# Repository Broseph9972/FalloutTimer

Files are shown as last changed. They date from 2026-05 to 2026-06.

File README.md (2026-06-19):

# FalloutTimer
Zine


Casing v5

---
The FalloutTimer™ is a simple timer that uses an RTC, A pi Pico, Some buttons, and some cheap 7 segment displays to tell you how much time is left in Hack club fallout!
(Can be used for other things as well)
# Assembly

Assembly is relatively simple, Solder the pico, buttons, caps, and RTC, into the spots they appear on the pcb/zine. look at the zine for info about how to solder the 7-seg display, then flash the firmware by holding down the boot button on the pico while plugging it in. then compile the code and drop the uf2 into the pico's flash. it should reboot and work. Thats really all you need.
--- 
# Usage
Simply set the time via the buttons on the bottom. left button controls days and hrs, left controls mins. seconds are always set to zero for simplicity. if you click the left button it will change hrs, if u hold it down, then it will change days. Thats basically it.
---
## Why?
I decided to make it because i need more time for fallout and it seemed like a simple project i could do to increase my amount of approved hours. also it looks cool as wall deco. ill probably bring it to fallout to show the amount of time left
It displays the time left in fallout with Day,Hour,Minutes,Seconds, similar to the fallout website. also i might get it to check streaks too maybe? <- no wifi so probably not. u would need a pico w aswell.

|Name |Price|Link |Quantity|Notes |
|---|-----|---|---|---|
|7 Segment display |$2.77|https://www.aliexpress.us/item/2255801097197605.html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 |1 |Comes with 8 digits built in. built for 0.56" |
|Pi Pico |$0.99|https://www.aliexpress.us/item/3256806652932348.html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 |1 |Lots of fakes, shouldnt matter. get usb-c if u want|
|PCB |$7.12|JLCPCB.com |1 |Upload the gerber from the repo. |
|DS3231M RTC |$1.39|https://www.aliexpress.us/item/3256807808551126.html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|1 |so u dont gotta reset the clock everytime |
|100nF Cap |$1.58|https://www.aliexpress.us/item/3256802327709422.html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 |1 |Technically optional, but idk |
|Pushbuttons |$0.99|https://www.aliexpress.us/item/2251832687083572.html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 |2 |For input |
|3d printed parts (optional)|$0 |N/A |1 |Not needed but just there ig |

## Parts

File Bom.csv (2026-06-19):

Name | Price | Link | Quantity | Notes
7 Segment display | $2.77 | https://www.aliexpress.us/item/2255801097197605.html | 1 | Comes with 8 digits built in. built for 0.56"
Pi Pico | $0.99 | https://www.aliexpress.us/item/3256806652932348.html | 1 | Lots of fakes, shouldnt matter. get usb-c if u want
PCB | $7.12 | JLCPCB.com | 1 | Upload the gerber from the repo.
DS3231M RTC | $1.39 | https://www.aliexpress.us/item/3256807808551126.html | 1 | so u dont gotta reset the clock everytime
100nF Cap | $1.58 | https://www.aliexpress.us/item/3256802327709422.html | 1 | Technically optional, but idk
Pushbuttons | $0.99 | https://www.aliexpress.us/item/2251832687083572.html | 1 | For buttons
3d printed parts (optional) | $0 | N/A | 1 | Not needed but just there ig
M2 screws and bolts | $7.58 | https://a.co/d/0hszMEHz | 1 | For mounting the enclosure / parts

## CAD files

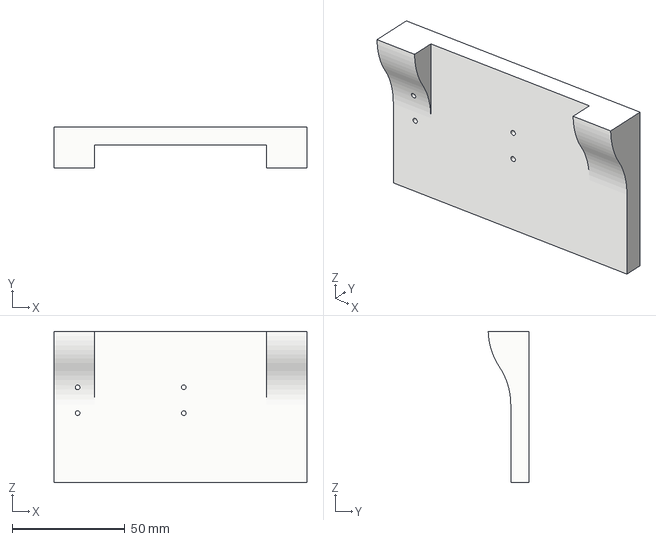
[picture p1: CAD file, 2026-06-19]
Cad/Casing.3mf
112.0 x 18.0 x 67.0 mm

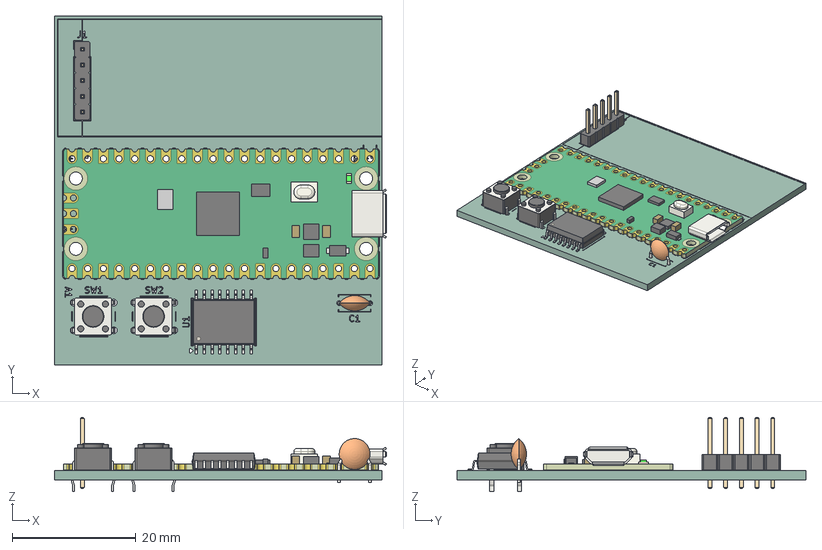
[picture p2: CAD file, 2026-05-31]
Cad/FalloutTimer.step
53.8 x 56.5 x 12.0 mm
SOIC-16W_7.5x10.3mm_P1.27mm
SW_PUSH_6mm x 2
C_Disc_D5.0mm_W2.5mm_P5.00mm
RaspberryPi_Pico_Module_KiCad
PinHeader_1x05_P2.54mm_Vertical
FalloutTimer_silkscreen x 2
FalloutTimer_PCB

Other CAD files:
Cad/Casing.f3d

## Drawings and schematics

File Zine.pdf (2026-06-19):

# FALLOUT TIMER!!

### Like this:

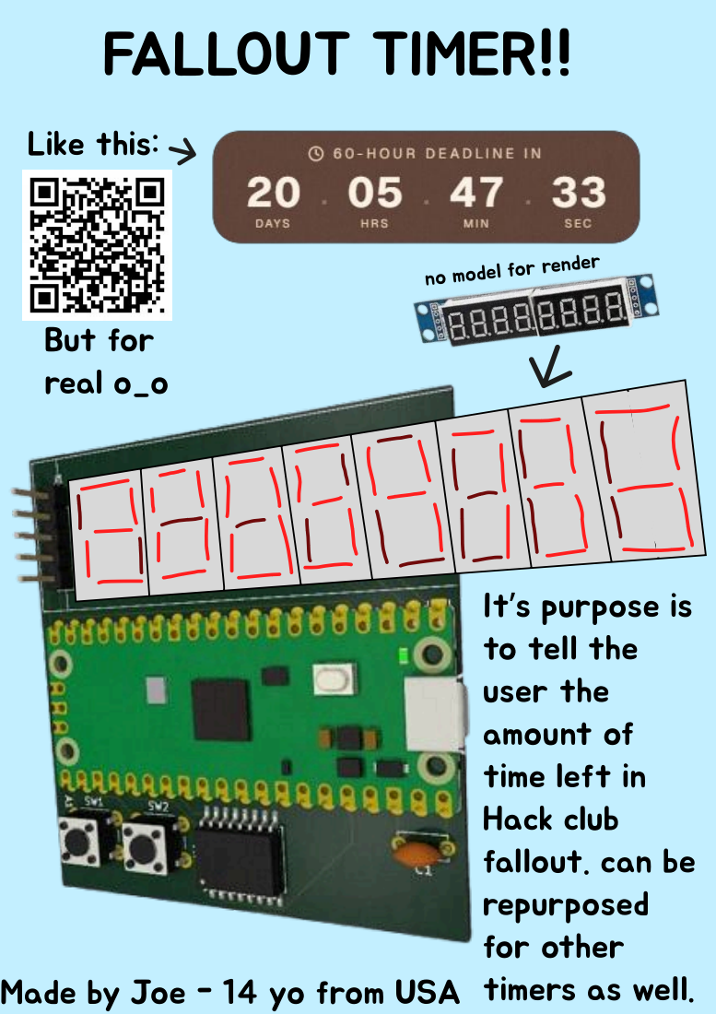
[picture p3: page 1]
But for; real o_o

no model for render

It’s purpose is
to tell the
user the
amount of
time left in
Hack club
fallout. can be
repurposed
for other
timers as well.

Made by Joe - 14 yo from USA

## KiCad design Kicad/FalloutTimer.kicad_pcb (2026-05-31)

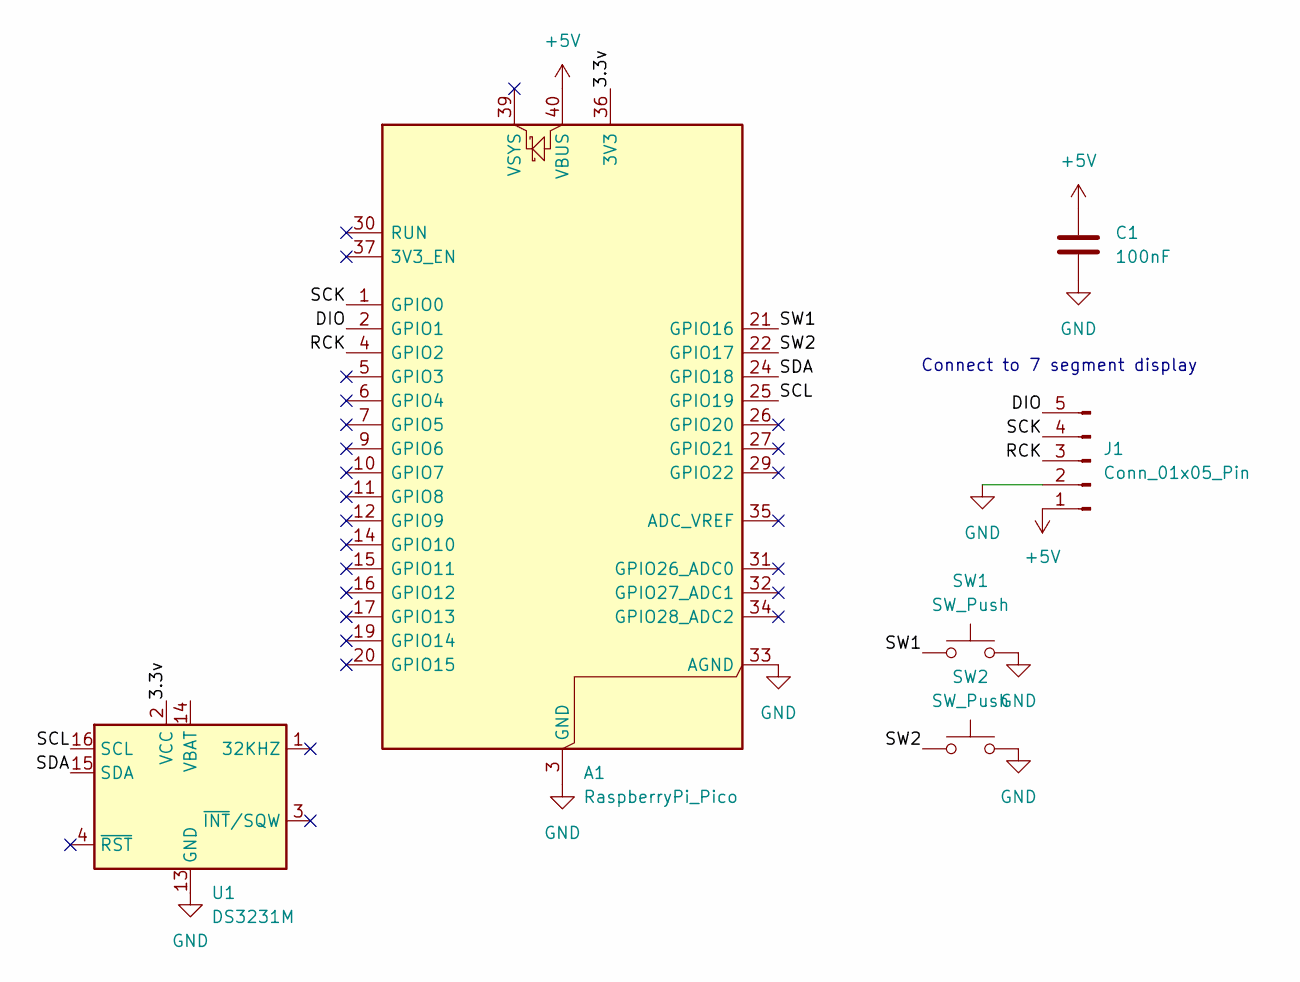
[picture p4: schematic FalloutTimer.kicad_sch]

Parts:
A1: RaspberryPi_Pico; RaspberryPi_Pico_Common_Unspecified
C1: 100nF; C_Disc_D5.0mm_W2.5mm_P5.00mm
J1: Conn_01x05_Pin; PinHeader_1x05_P2.54mm_Vertical
SW1, SW2: SW_Push; SW_PUSH_6mm
U1: DS3231M; SOIC-16W_7.5x10.3mm_P1.27mm

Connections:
+5V: A1.40 (VBUS), C1.1, J1.1
/3.3v: A1.36 (3V3), U1.2 (VCC)
/DIO: A1.2 (GPIO1), J1.5
/RCK: A1.4 (GPIO2), J1.3
/SCK: A1.1 (GPIO0), J1.4
/SCL: A1.25 (GPIO19), U1.16 (SCL)
/SDA: A1.24 (GPIO18), U1.15 (SDA)
/SW1: A1.21 (GPIO16), SW1.1
/SW2: A1.22 (GPIO17), SW2.1
GND: A1.3 (GND), A1.8 (GND), A1.13 (GND), A1.18 (GND), A1.23 (GND), A1.28 (GND), A1.33 (AGND), A1.38 (GND), C1.2, J1.2, SW1.2, SW2.2, U1.5 (GND), U1.6 (GND), U1.7 (GND), U1.8 (GND), U1.9 (GND), U1.10 (GND), U1.11 (GND), U1.12 (GND), U1.13 (GND)

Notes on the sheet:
Connect to 7 segment display

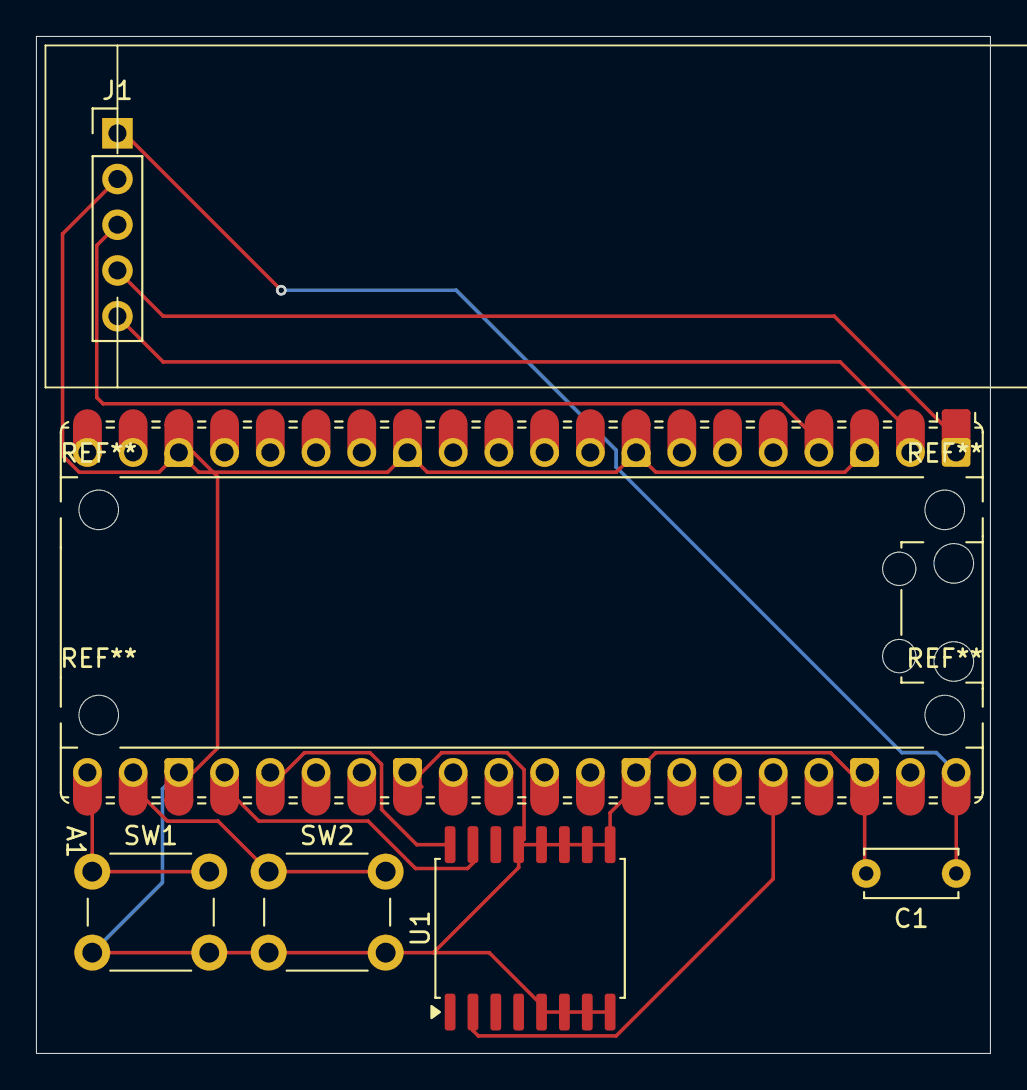
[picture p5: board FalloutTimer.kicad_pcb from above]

Board: 2 copper layers, 53.0 x 56.5 mm, 6 parts (0 on the bottom side), 10 nets.

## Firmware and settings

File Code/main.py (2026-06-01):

import board
import busio
import time
import digitalio
from adafruit_ds3231 import DS3231

# I2C for RTC (SDA=GPIO18, SCL=GPIO19)
i2c = busio.I2C(scl=board.GP19, sda=board.GP18)
rtc = DS3231(i2c)

# 74HC595 shift registers for 8 7-segment displays
# SCK=GPIO0 (clock), DIO=GPIO1 (data), RCK=GPIO2 (latch)
sck = digitalio.DigitalInOut(board.GP0)
sck.direction = digitalio.Direction.OUTPUT

dio = digitalio.DigitalInOut(board.GP1)
dio.direction = digitalio.Direction.OUTPUT

rck = digitalio.DigitalInOut(board.GP2)
rck.direction = digitalio.Direction.OUTPUT

# 7-segment display patterns (common cathode, DP on bit 7)
SEGMENTS = {
    0: 0b00111111,  # 0
    1: 0b00000110,  # 1
    2: 0b01011011,  # 2
    3: 0b01001111,  # 3
    4: 0b01100110,  # 4
    5: 0b01101101,  # 5
    6: 0b01111101,  # 6
    7: 0b00000111,  # 7
    8: 0b01111111,  # 8
    9: 0b01101111,  # 9
    10: 0b00000000  # blank
}

# Pushbuttons (GPIO16 and GPIO17, pulled to GND)
button_left = digitalio.DigitalInOut(board.GP16)
button_left.direction = digitalio.Direction.INPUT
button_left.pull = digitalio.Pull.UP

button_right = digitalio.DigitalInOut(board.GP17)
button_right.direction = digitalio.Direction.INPUT
button_right.pull = digitalio.Pull.UP

# Timer state (in seconds)
time_remaining = 0
setting_mode = False
blink_state = False
blink_time = 0
display_buffer = [10, 10, 10, 10, 10, 10, 10, 10]

def shift_out_byte(byte):
    """Shift out 8 bits to 74HC595"""
    for i in range(8):
        dio.value = (byte >> (7 - i)) & 1
        time.sleep(0.00005)
        sck.value = 1
        time.sleep(0.00005)
        sck.value = 0

def latch():
    """Latch data into output registers"""
    rck.value = 1
    time.sleep(0.0001)
    rck.value = 0

def shift_out_bytes(bytes_list):
    """Shift out multiple bytes (for chaining 74HC595s)"""
    for byte in reversed(bytes_list):  # Reverse for correct bit order
        shift_out_byte(byte)
    latch()

def seconds_to_display(seconds):
    """Convert seconds to day:hour:minute:second format"""
    days = seconds // 86400
    hours = (seconds % 86400) // 3600
    minutes = (seconds % 3600) // 60
    secs = seconds % 60
    return days, hours, minutes, secs

def update_display(days, hours, minutes, secs):
    """Update display buffer with DD:HH:MM:SS"""
    global display_buffer
    display_buffer = [
        days // 10,
        days % 10,
        hours // 10,
        hours % 10,
        minutes // 10,
        minutes % 10,
        secs // 10,
        secs % 10
    ]

def render_display():
    """Send display buffer to 74HC595s"""
    segments = [SEGMENTS.get(d, SEGMENTS[10]) for d in display_buffer]
    shift_out_bytes(segments)

def display_blink():
    """Blink display when timer reaches 0"""
    global blink_state, blink_time
    current_time = time.monotonic()
    if current_time - blink_time > 0.5:
        blink_state = not blink_state
        blink_time = current_time
        if blink_state:
            display_buffer[:] = [10] * 8
        else:
            update_display(0, 0, 0, 0)
    render_display()

def check_both_buttons_held():
    """Check if both buttons are held down"""
    return not button_left.value and not button_right.value

# Main loop
last_second_update = time.monotonic()
left_pressed = False
right_pressed = False
button_held_time = 0

while True:
    current_time = time.monotonic()
    both_held = check_both_buttons_held()
    
    # Enter/exit setting mode
    if both_held and not setting_mode:
        setting_mode = True
        button_held_time = current_time
    elif setting_mode and not both_held:
        setting_mode = False
    
    if setting_mode:
        # In setting mode - adjust time with button presses
        if not button_left.value and not left_pressed:
            # Left button: add hour
            left_pressed = True
            time_remaining = min(time_remaining + 3600, 9999999)
            print(f"Timer: {time_remaining}s (+1h)")
            time.sleep(0.1)
        elif button_left.value:
            left_pressed = False
        
        if not button_right.value and not right_pressed:
            # Right button: add minute (reset seconds), or add day if held
            right_pressed = True
            hold_duration = current_time - button_held_time
            if hold_duration > 1.0:
                # Long hold: add day
                time_remaining = min(time_remaining + 86400, 9999999)
                print(f"Timer: {time_remaining}s (+1d)")
            else:
                # Short press: add minute, reset seconds
                time_remaining = (time_remaining // 60 + 1) * 60
                time_remaining = min(time_remaining, 9999999)
                print(f"Timer: {time_remaining}s (+1m)")
            time.sleep(0.1)
        elif button_right.value:
            right_pressed = False
        
        # Display time being set
        days, hours, minutes, secs = seconds_to_display(time_remaining)
        update_display(days, hours, minutes, secs)
        render_display()
    
    else:
        # Normal countdown mode
        if current_time - last_second_update >= 1.0:
            if time_remaining > 0:
                time_remaining -= 1
            last_second_update = current_time
        
        # Display countdown or blink
        if time_remaining > 0:
            days, hours, minutes, secs = seconds_to_display(time_remaining)
            update_display(days, hours, minutes, secs)
            render_display()
        else:
            display_blink()

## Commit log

2026-05-28 some stuffs
    [FalloutTimer.kicad_pcb, FalloutTimer.kicad_sch]
2026-05-29 PCB and Schema mostly done
    [FalloutTimer.kicad_pcb, FalloutTimer.kicad_sch]
2026-05-30 added an outline for the display on the pcb
    [FalloutTimer.kicad_pcb]
2026-05-31 Finsihed PCB.
    asdasd
    [FalloutTimer.kicad_pcb, freerouting.dsn, temp-freerouting.dsn]
2026-05-31 Added the kicad gitignore so i dont get .history changes.
2026-05-31 Janky hopefully precise enough screw holes
    i basically just put them where the pico holes are.
    [FalloutTimer.kicad_pcb, FalloutTimer.step]
2026-05-31 new .step
    [FalloutTimer.step]
2026-06-04 New bom
2026-06-04 Added Case
    [FalloutTimer Case.step]
2026-06-19 Add M2 screws and bolts to BOM CSV
    [Bom.csv]
2026-06-19 Good Cad
    [Casing.3mf, Casing.f3d, FalloutTimer Case.step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]
